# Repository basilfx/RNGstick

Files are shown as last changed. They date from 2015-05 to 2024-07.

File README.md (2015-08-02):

# RNGstick
Entropy stick for experimenting, generating and evaluating true random numbers.

Status: evaluating prototype.

## Introduction
This project provides a hardware random number generation with a customizable firmware for experimenting. A NE555 free-running oscillator is used, of which the clock drift is measured and used as a source of randomness. The stick can be used for feeding the Linux entropy pool for random numbers.

The firmware is configurable via a built-in command line.

## Background
The idea for this project is from a research project I conducted during my master's programme. Together with two others, we did a research on using accelerometers from mobile phones for generating true random numbers.

### True randomness
True random numbers (in contrast to pseudorandom numbers) are unpredictable. Given a number, the next number is not predictable and not linked to it. Computers cannot generate true random numbers via an algorithm, but they can observe physical events and extract uncertainty (entropy). For instance, mouse movement, disk access time and network traffic times are considered unpredictable. There is one problem: these events may occur not frequent enough, which means that the pool of entropy will exhaust. For general purpose random numbers, this is not a big deal, but for generating cryptographic keys, this becomes a problem.

An operating system does not directly generate numbers from this pool, but uses a pseudorandom algorithm that is seeded with the collected entropy. On Linux, `/dev/random` will block when the entropy pool is exhausted, but `/dev/urandom` won't. A quick experiment is to `cat /dev/random` and move the mouse around. You will notice the rate of numbers will increase (at least on Linux without HWRNG).

### Project rationale
In the last few years, processor manufacturers have incorporated hardware random number generators in processors. A kernel can use this source directly to generate random numbers, or to feed the entropy pool. However, with recent NSA leakings, some OS's have already [announced](http://www.theregister.co.uk/2013/12/09/freebsd_abandoning_hardware_randomness/) to not trust these output sources directly.

This project is an open-source attempt to generate random numbers of sufficien quality, using a low number of hardware parts. It is based on [this](http://1474orchard.ca/projects/?x=entry:entry120926-185104) blog post, where the author is using a NE555 free-running oscillator and uses the clock drift as a source of randomness. An Arduino samples the output of the NE555 regularly, which is a point on the waveform. Clock drift is affected by temperature, part stability, voltage and many more factors, that are unpredictable in some sense. In short, given two waveforms they won't be the same as one period may be a tiny bit shorter or longer. Using hardware parts with more tolerance (thus more error) is preferred.

The next two graphs the P(x) values of the ADC sample distribution over the full ADC sample space (10 bits) and the bit distribution (again, 10 bits). Both graphs match the ones from the blog post. Note how the lower 5 bits are uniformly distributed.

board

board

I have used this design and created an USB stick with a customizable firmware for generating random bytes. In addition to the original design, the NE555 can be reset before each iteration (to target the same sample point) and the voltage reference for the ADC is customizable. Many parameters can be tuned to generate random numbers in a different way. The following features are available:

* Sampling: batch-samples, or per-sample
* Sample processing: masking, shifting and delays
* Bit extracting: one-majority, XOR, or raw bits
* Extraction: (Improved) Von Neumann bias removal, or none
* Generating: SHA-1, or none
* Bucketing: buffer bytes to output chuncks, or continuously
* Outputting: (Binary) bytes or bits

To give an idea of the output, the following distribution of the P-values was created, using ones-majority over the lower five bits and bias removal using Improved Von Neumann, without any generator. One should be careful to call the output random from this graph only, because a predictable sequence from 0-255 over and over would generate a similar graph.

board

More graphs can be found [here](https://github.com/basilfx/RNGstick/blob/master/docs/Graphs.md).

### Testing
The problem with random numbers is that you cannot prove they are random. However, there are statistical tests which can indicate if a sequence of random numbers is 'random' enough. Even a sequence of numbers that doesn't look random could be random, as the random number generator could produce this sequence.

Three programs are available to check the produced sequences. The first is `ent`, which calculates the Entropy, Chi-square Distribution and the Arithmetic Mean Value. The second one is `rngtest`, which implements the FIPS 140-2 tests. The last one is `dieharder`, which implements a lot of different tests.

Sidenote: SHA-1 will generate more bytes of randomness for one input byte. In some sense it is a pseudorandom algorithm. Given the internal state, the next output bytes can be predicted if the next input byte is predictable. Since SHA-1 is a computational strong hash function, it will most-certainly pass all statistical tests by default.

TODO add test results here

## Contents
* Eagle schematic and PCB
* Arduino firmware

## Eagle

### Bill of materials
| Part | Value | Device | Package |
|---|---|---|---|
| C1 | 22pF | C-EUC0603K | C0603K |
| C2 | 22pF | C-EUC0603K | C0603K |
| C3 | 22pF | C-EUC0603K | C0603K |
| C4 | 22pF | C-EUC0603K | C0603K |
| C5 | 10nF | C-EUC0603K | C0603K |
| C6 | 100nF | C-EUC0603K | C0603K |
| C7 | 100nF | C-EUC0603K | C0603K |
| C8 | 100nF | C-EUC0603K | C0603K |
| D1 | | PESD5V0U1BB | SOD523 |
| D2 | | PESD5V0U1BB | SOD523 |
| IC1 | | NE555D | SO08 |
| JP1 | USB-A-H | USB-A-H | USB-A-H |
| JP4 | M02PTH | M02PTH | 1X02 |
| R1 | 5K | TRIM_EU-3223W | 3223W |
| R2 | 330R | R-EU_R0603 | R0603 |
| R3 | 10k | R-EU_R0603 | R0603 |
| R4 | 10k | R-EU_R0603 | R0603 |
| U2 | | CH340G | SOIC16 |
| U1 | | ATMEGA328 | TQFP32-08 |
| Q1 | 16MHz | MT-OSCILLATOR | MT |
| Q2 | 12MHz | MT-OSCILLATOR | MT |

### Board render
Render of the stick. It measures 1.45x0.65 inch.

board

## Firmware
The firmware resides in `firmware/RNG`. You will need a copy of the [CommandLine](https://github.com/basilfx/Arduino-CommandLine) library and the [Cruiptosuit](https://github.com/spaniakos/Cryptosuite/) library.

Modify the `Arduino/CommandLine/CommandLine.h` file to reflect the following (see its `README.md` file why):

```
#define COMMANDLINE_COUNT 24
#define COMMANDLINE_BUFFER 24
// #define COMMANDLINE_PRE_POST
#define COMMANDLINE_HISTORY 0
```

## Software

### Configuration
To configure the stick, short JP4 while booting. A setup prompt should appear. Use the `help` command to list all available commands. Do not forget to save a change using the `save` command. Use `defaults` or `load` respectively.

### Installation
This will install `rng-tools` for feeding the random numbers back into the kernel. It applies to Ubuntu 15.04, but others will work fine too. `/dev/ttyACM0` is assumed to be the RNGstick.

* Instal `rng-tools` via `sudo apt-get install rng-tools`
* Change `/etc/defaults/rng-tools`
 * Add `stty -F /dev/ttyACM0 115200 time 25`
 * Add `HRNGDEVICE=/dev/ttyACM0`
* Restart `rng-tools` with `sudo service rng-tools restart`
* Observe `/proc/sys/kernel/random/entropy_avail`

## License
See the `LICENSE` file (MIT license).

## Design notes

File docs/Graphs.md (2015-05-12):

# Output graphs

## ADC Values
Graphs below are the ADC P(x) distributions.

board

board

board

board

## Bit values
Graphs below are the individual P(x) value distributions.

board

## RNG values
Graphs below are the P(x) value distributions of the RNG output values (1-256).

board

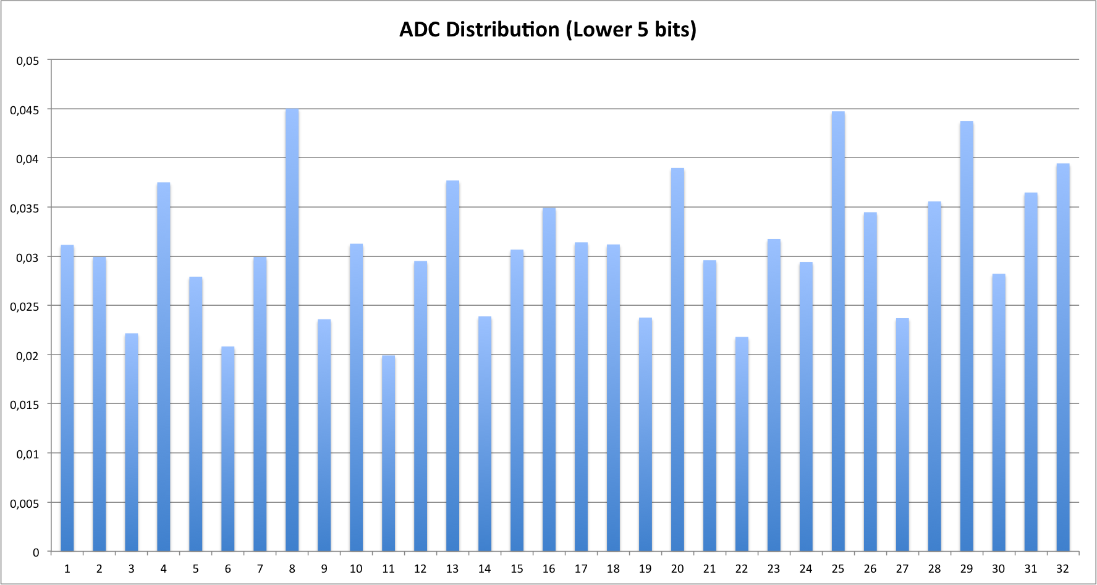
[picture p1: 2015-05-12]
docs/adc_5bits.png

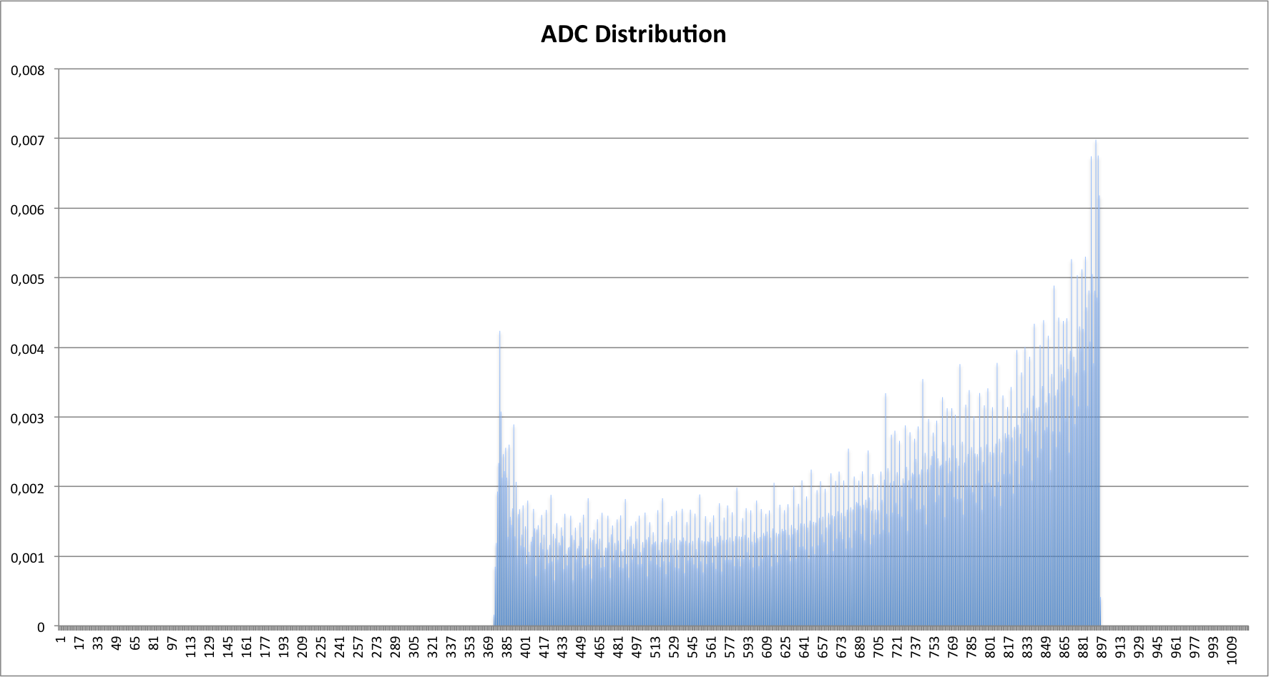
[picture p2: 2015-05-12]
docs/adc_10bits.png

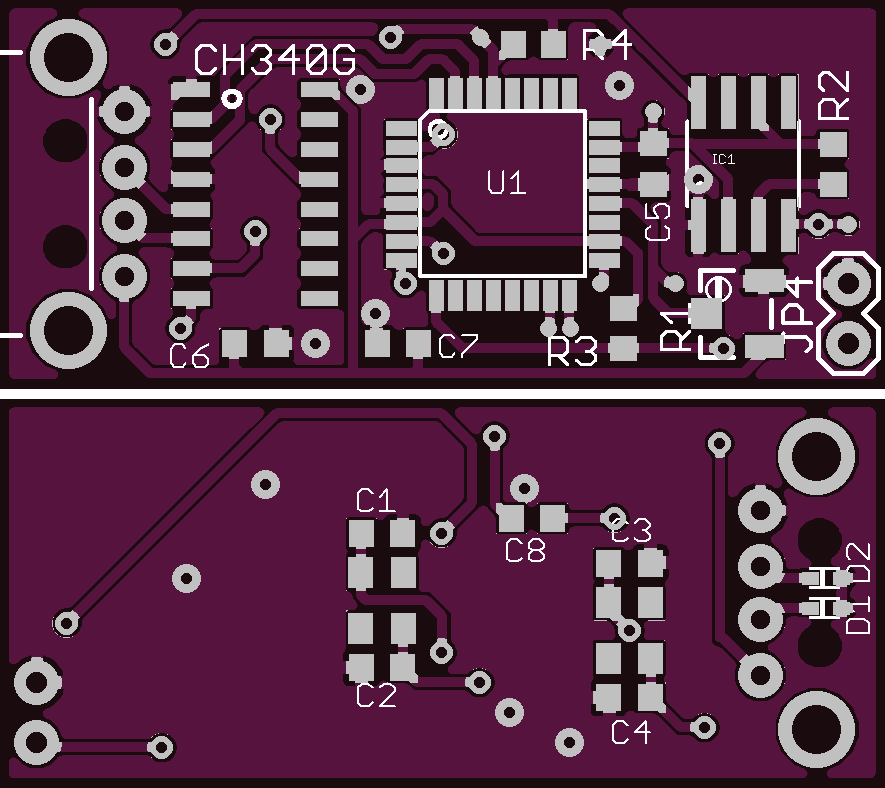
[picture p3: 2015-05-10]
docs/stick.png

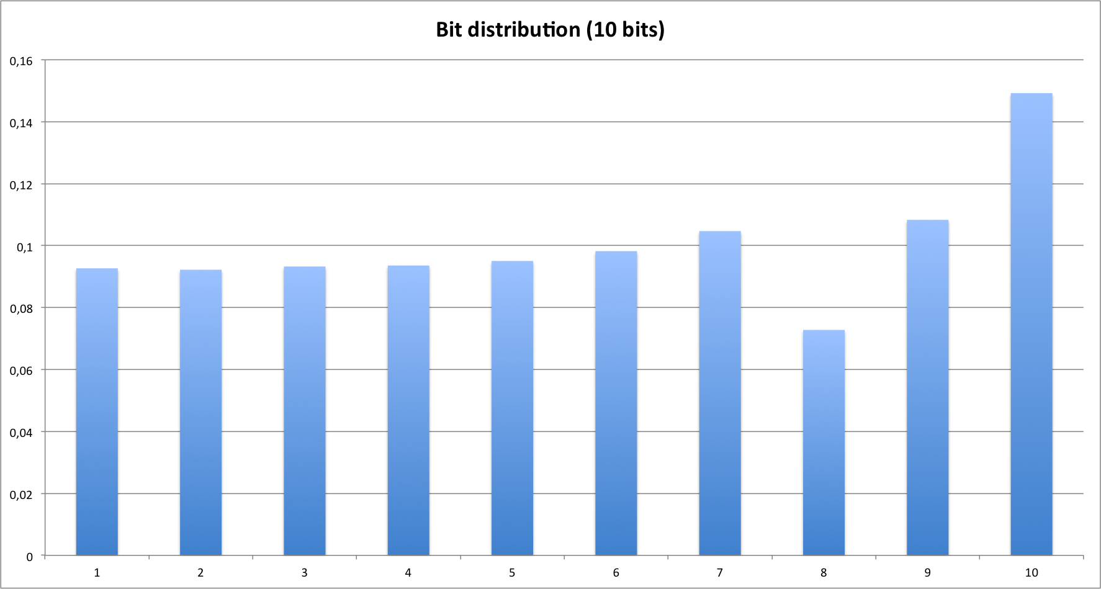
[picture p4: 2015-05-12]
docs/bit_distribution.png

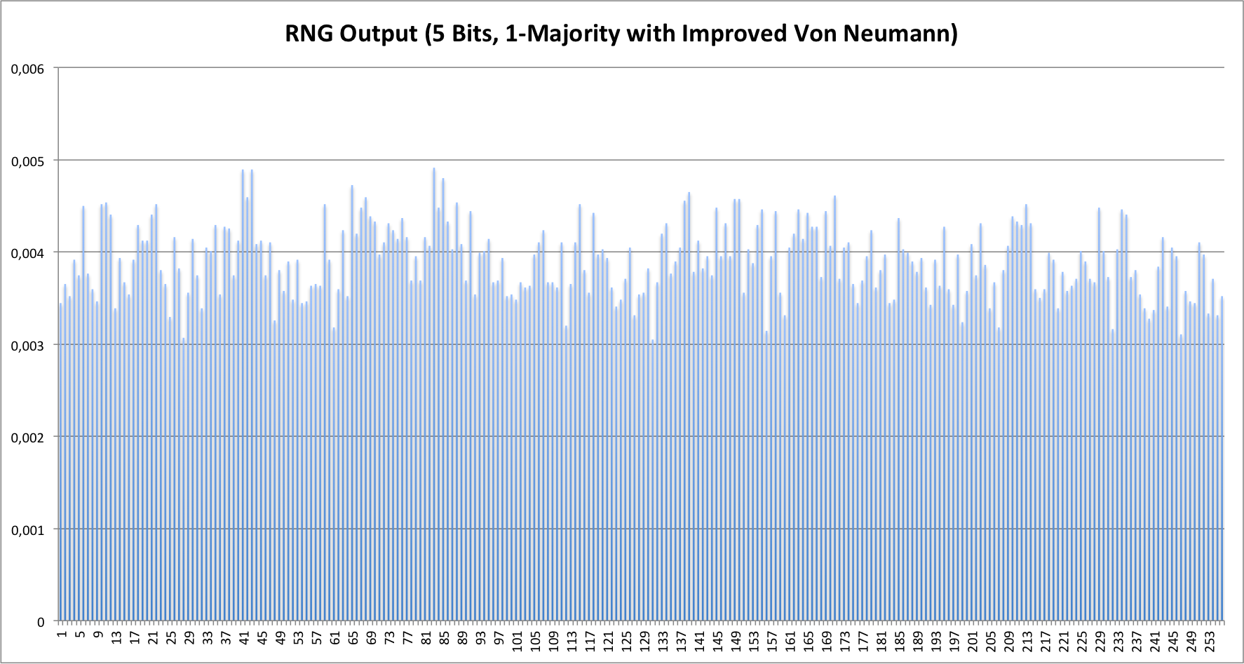
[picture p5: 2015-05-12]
docs/rng_out.png

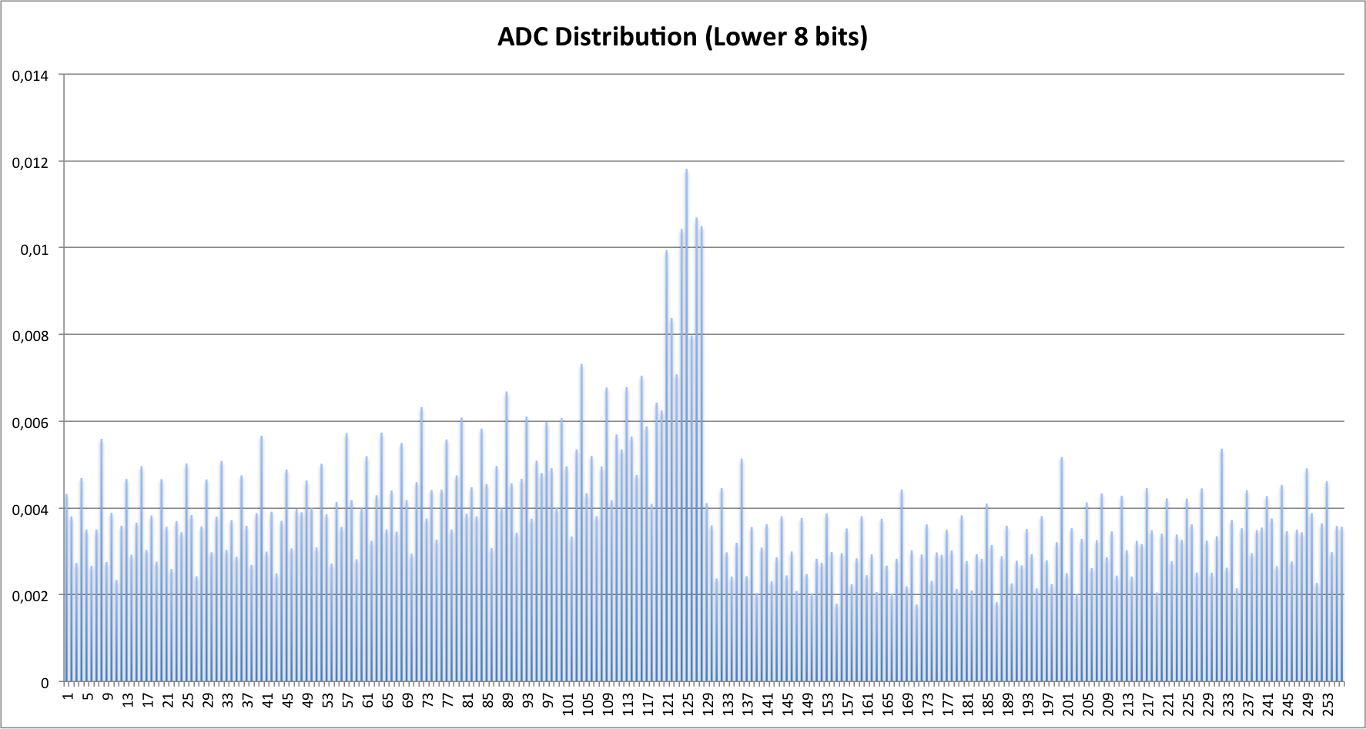
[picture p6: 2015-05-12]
docs/adc_8bits.png

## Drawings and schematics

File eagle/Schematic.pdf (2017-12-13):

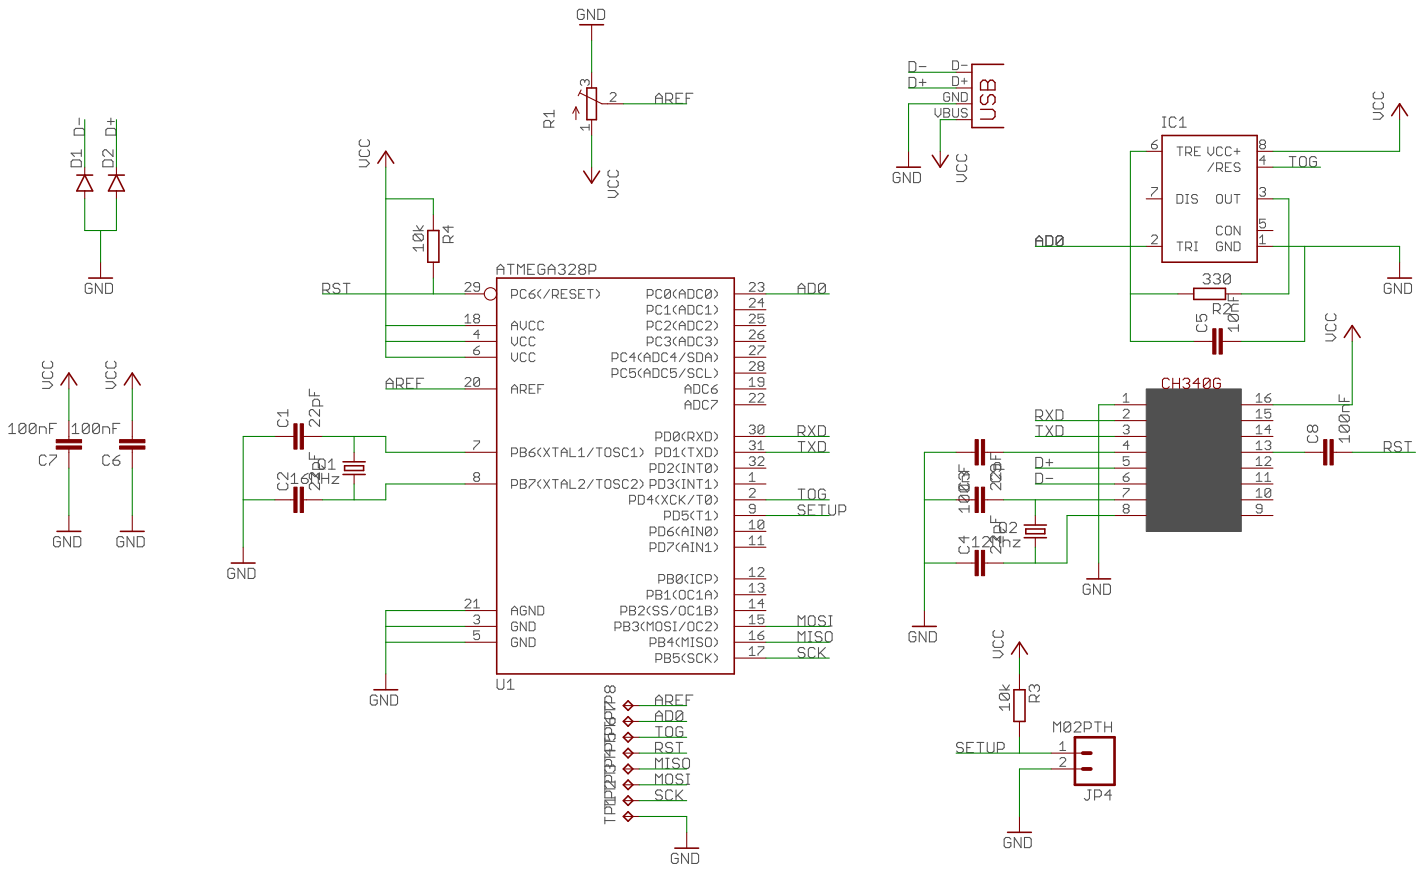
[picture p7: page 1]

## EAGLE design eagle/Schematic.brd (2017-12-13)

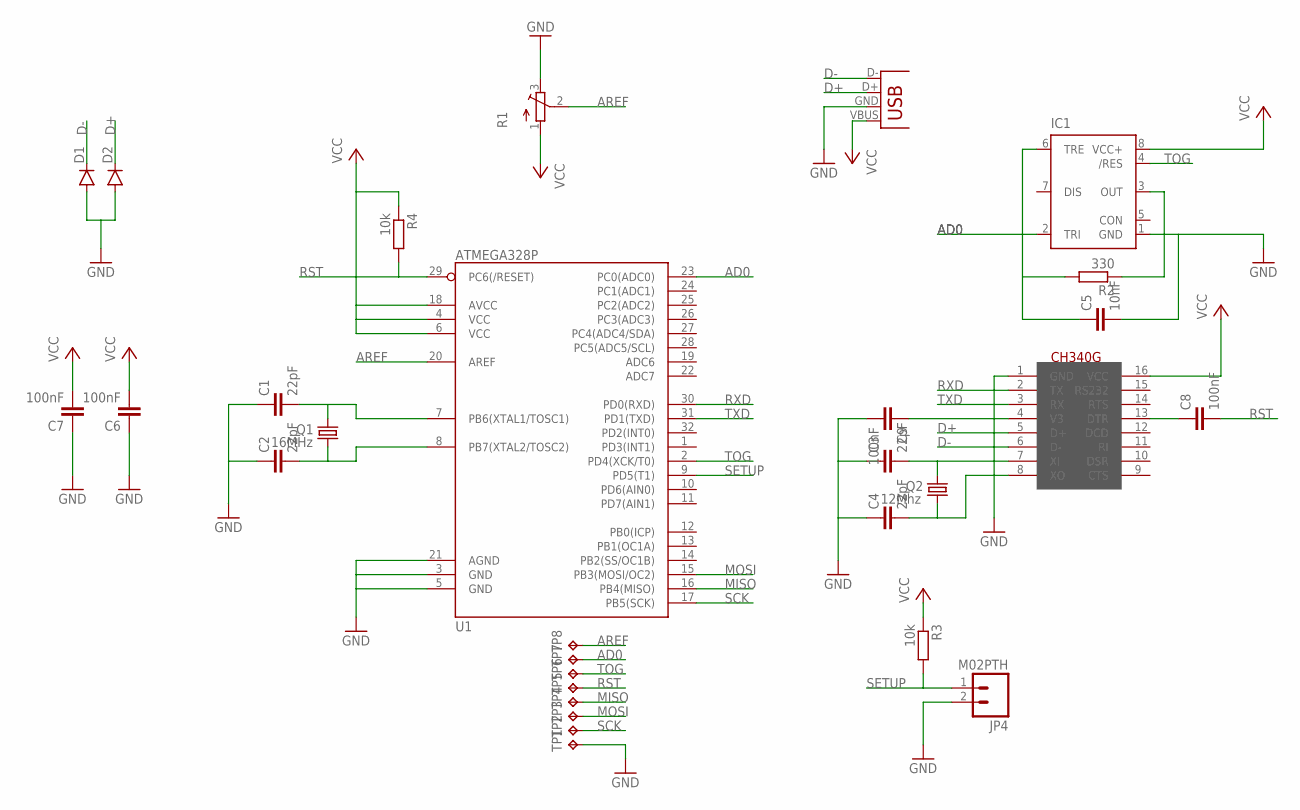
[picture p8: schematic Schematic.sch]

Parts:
C1, C2, C3, C4: 22pF; C0603K
C5: 10nF; C0603K
C6, C7, C8, C9: 100nF; C0603K
D1, D2: DIODESOD523; SOD523
IC1: NE555D; SO08
JP1: USB-A-H
JP4: M02PTH; 1X02
Q1: 16MHz; MT
Q2: 12Mhz; MT
R1: TRIM_EU-3223W; 3223W
R2: 330; R0603
R3, R4: 10k; R0603
TP1, TP2, TP3, TP4, TP5, TP6, TP7, TP8: TPTP10R; TP10R
U1: ATMEGA328P; TQFP32-08
U2: CH340G; SOIC16

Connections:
AD0: C5.1, IC1.2 (TRI), IC1.6 (TRE), R2.2, TP7.TP, U1.23 (PC0(ADC0))
AREF: R1.2 (S), TP8.TP, U1.20 (AREF)
D+: D2.C, JP1.D+ (D-), U2.5 (D+)
D-: D1.C, JP1.D- (D+), U2.6 (D-)
GND: C1.1, C2.1, C3.1, C4.1, C5.2, C6.1, C7.1, C9.2, D1.A, D2.A, IC1.1 (GND), JP1.GND (VBUS), JP4.2, R1.3 (E), TP1.TP, U1.3 (GND), U1.5 (GND), U1.21 (AGND), U2.1 (GND)
MISO: TP4.TP, U1.16 (PB4(MISO))
MOSI: TP3.TP, U1.15 (PB3(MOSI/OC2))
unnamed: IC1.3 (OUT), R2.1
unnamed: C3.2, Q2.3 (2), U2.7 (XI)
unnamed: C4.2, Q2.1, U2.8 (XO)
unnamed: C1.2, Q1.3 (2), U1.7 (PB6(XTAL1/TOSC1))
unnamed: C2.2, Q1.1, U1.8 (PB7(XTAL2/TOSC2))
unnamed: C8.1, U2.13 (DTR)
unnamed: C9.1, U2.4 (V3)
RST: C8.2, R4.2, TP5.TP, U1.29 (PC6(/RESET))
RXD: U1.30 (PD0(RXD)), U2.2 (TX)
SCK: TP2.TP, U1.17 (PB5(SCK))
SETUP: JP4.1, R3.2, U1.9 (PD5(T1))
TOG: IC1.4 (/RES), TP6.TP, U1.2 (PD4(XCK/T0))
TXD: U1.31 (PD1(TXD)), U2.3 (RX)
VCC: C6.2, C7.2, IC1.8 (VCC+), JP1.VBUS (GND), R1.1 (A), R3.1, R4.1, U1.4 (VCC), U1.6 (VCC), U1.18 (AVCC), U2.16 (VCC)

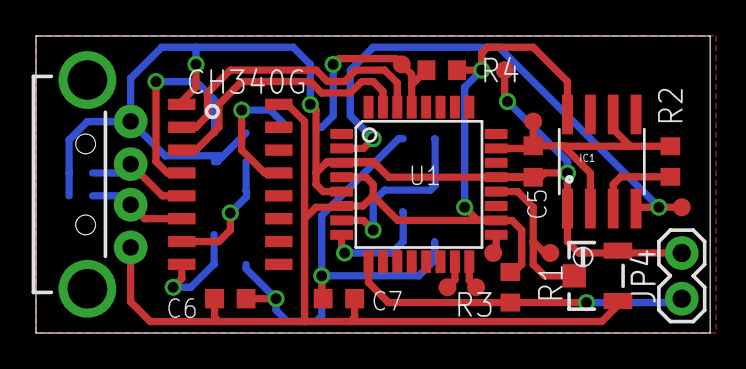
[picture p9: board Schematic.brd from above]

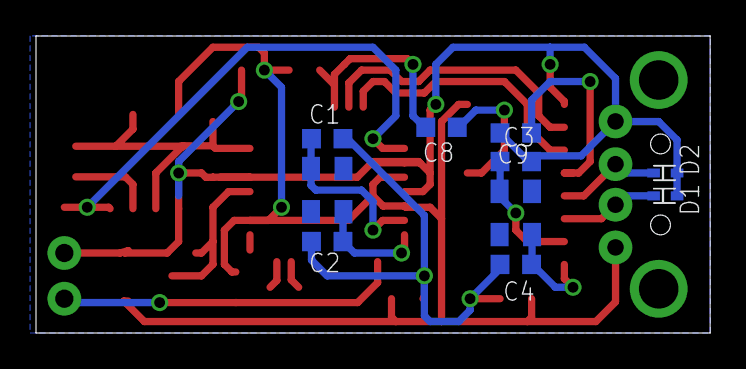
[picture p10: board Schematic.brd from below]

Board: 2 copper layers, 37.5 x 16.5 mm, 30 parts (10 on the bottom side), 21 nets.

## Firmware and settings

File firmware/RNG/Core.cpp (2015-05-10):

#include "Core.h"

/**
 * Sample bucket
 */
volatile uint16_t sampleBucket[256];

/**
 * Process buffer
 */
volatile uint16_t processBuffer[2];
volatile uint8_t processBufferCount;

/**
 * Extraction buffer
 */
volatile uint16_t extractBuffer;
volatile uint8_t extractBufferCount;

/**
 * Generate buffer
 */
volatile uint16_t generateBuffer;
volatile uint8_t generateBufferCount;

/**
 * Output buffer
 */
volatile uint16_t outputBuffer;
volatile uint8_t outputBufferCount;

/**
 * Output bucket
 */
volatile uint8_t outputBucket[256];
volatile uint16_t outputBucketIndex;

void output(uint8_t value) 
{ 
  if (configuration.outputMode == 1) {
    Serial.write(value);
  } else if (configuration.outputMode == 2) {
    Serial.print(value, DEC);
  } else if (configuration.outputMode == 3) {
    Serial.println(value, DEC); 
  }
}

void bucket(uint8_t value)
{
  outputBucket[outputBucketIndex] = value;
  outputBucketIndex++;
  
  if (outputBucketIndex >= configuration.outputBucket) {
    while (true) {
      outputBucketIndex--;
      output(outputBucket[outputBucketIndex]);
      
      if (outputBucketIndex == 0) {
        break;
      }
    }
  }
}

void collect(uint8_t value, uint8_t count)
{ 
  outputBuffer = (outputBuffer << count) | value;
  outputBufferCount = outputBufferCount + count;
  
  while (outputBufferCount > 7) {
    if (configuration.output == 1) {
      for (uint8_t i = 0; i < 8; i++) {
        bucket((uint8_t) (outputBuffer & 0x01));
        outputBuffer = outputBuffer >> 1;
      }
    } else if (configuration.output == 2) {
      bucket((uint8_t) (outputBuffer & 0xFF));
      outputBuffer = outputBuffer >> 8; 
    }
    
    outputBufferCount = outputBufferCount - 8; 
  }
}

void generate(uint8_t value, uint8_t count)
{
  if (configuration.generator == 1) {
    collect(value, count);
  } else if (configuration.generator == 2) {
    generateBuffer = (generateBuffer << count) | value;
    generateBufferCount = generateBufferCount + count;
    
    while (generateBufferCount > 7) {
      Sha1.print((uint8_t) (generateBuffer & 0xFF));
      uint8_t* result = Sha1.result();
      
      for (uint32_t i = 0; i < 20; i++) {
         collect(result[i], 8);
      }
      
      generateBuffer = generateBuffer >> 8;
      generateBufferCount = generateBufferCount - 8;
    }
  }
}

void extract(uint8_t value, uint8_t count)
{ 
  if (configuration.extractor == 1) {
    generate(value, count);
  } else if (configuration.extractor == 2 || configuration.extractor == 3) {
    extractBuffer = (extractBuffer << count) | value;
    extractBufferCount = extractBufferCount + count;
  
    while (extractBufferCount > 3) {
      if (configuration.extractor == 2) {
        generate(VON_NEUMANN[extractBuffer & 0x0F][0], VON_NEUMANN[extractBuffer & 0x0F][1]);
      } else if (configuration.extractor == 3) {
        generate(IMPROVED_VON_NEUMANN[extractBuffer & 0x0F][0], IMPROVED_VON_NEUMANN[extractBuffer & 0x0F][1]);
      }
     
      extractBuffer = extractBuffer >> 4;
      extractBufferCount = extractBufferCount - 4; 
    }
  }
}

void process(uint16_t sample)
{
  sample = (sample & configuration.sampleMask) >> configuration.sampleShift;
  
  if (configuration.mode == 1) {
    extract(sample, configuration.sampleTake);
  } else if (configuration.mode == 3) {
    processBuffer[processBufferCount] = sample;
    processBufferCount++;

    if (processBufferCount == 2) {
      extract(processBuffer[0] ^ processBuffer[1], configuration.sampleTake);
    }
  } else if (configuration.mode == 2) {
    uint8_t count = 0;
    
    for (uint8_t i = 0; i < configuration.sampleTake; i++) {
      if (sample & (1 << i)) {
        count++;
      }
    }

    extract(count > (configuration.sampleTake / 2) ? 1 : 0, 1);
  }
}

void loop()
{
  // Reset the NE555
  if (configuration.sampleReset == 1) {
    digitalWrite(4, LOW);
    delayMicroseconds(configuration.delayHold);
    digitalWrite(4, HIGH);
    delayMicroseconds(configuration.delaySkip);
  }
  
  // Take samples
  for (uint16_t i = 0; i < configuration.sampleMultiple; i++) {
    // Gather samples
    for (uint16_t j = 0; j < configuration.sampleBucket; j++) {
      sampleBucket[j] = analogRead(A0);
    }
    
    // Process samples
    for (uint16_t j = 0; j < configuration.sampleBucket; j++) {
      process(sampleBucket[j]);
    }
  }
  
  // Round delay
  delayMicroseconds(configuration.delayRound); 
}

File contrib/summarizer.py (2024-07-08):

import sys
import os
import formic

# Tests to disable
DISABLED_TESTS = [
    "dab_bytedistrib",
    "marsaglia_tsang_gcd",
    "rgb_minimum_distance",
    "rgb_kstest_test"
]

PROPERTIES = {
    "sampleReset": ("Sample reset", lambda x: "Yes" if x else "No"),
    "sampleBucket": ("Sample bucket size", lambda x:  "%s b" % x),
    "sampleMultiple": ("Sample multiple", lambda x: "%s b" % x),
    "delayHold": ("Sample hold", lambda x: "%s us" % x),
    "delaySkip": ("Sample skip", lambda x:  "%s us" % x),
    "delayRound": ("Delay round", lambda x: "%s us" % x),
    "sampleMask": ("Sample mask", hex),
    "sampleShift": ("Sample shift", str),
    "sampleTake": ("Sample take", str),
    "mode": ("Mode", lambda x: "Raw" if x == 1 else "Ones-majority"),
    "extractor": ("Extractor", lambda x: "None" if x == 1 else "Von Neumann" if x == 2 else "Improved Von Neumann"),
    "generator": ("Generator", lambda x: "None" if x == 1 else "SHA-1"),
    "output": ("Output", lambda x: "Bits" if x == 1 else "Bytes"),
    "outputMode": ("Output mode", lambda x: "Raw" if x == 1 else "ASCII" if x == 2 else "ASCII + Newline"),
    "outputBucket": ("Output bucket", lambda x: "%s b" % x)
}


def main(argv):
    if len(argv) < 2:
        sys.stdout.write("Syntax: %s <input_dir>\n" % argv[0])
        return 1

    input_dir = os.path.abspath(argv[1])

    # Find files
    file_set = formic.FileSet(include="**/*.diehard", directory=input_dir)
    filenames = list(file_set)

    # Print header
    sys.stdout.write("ID,File size,ENT,Entropy,Chi-square,Mean,Monte-Carlo-Pi,Serial-Correlation,DIEHARDER,Total,Passed,Failed,Weak,CONFIGURATION,")
    sys.stdout.write(",".join([x[0] for x in PROPERTIES.itervalues()]) + "\n")

    for filename in filenames:
        # Resolve filenames
        test_id = os.path.basename(filename).rsplit(".", 1)[0]
        filename_dh = filename
        filename_conf = filename.rsplit(".", 1)[0] + ".txt"
        filename_ent = filename.rsplit(".", 1)[0] + ".ent"
        filename_data = filename.rsplit(".", 1)[0] + ".bin"

        file_size = os.stat(filename_data).st_size

        # Initialize counters
        total = 0
        weak = 0
        failed = 0
        passed = 0
        state = 0

        # Read DIEHARDER file and scan for test results
        with open(filename_dh, "r") as fp:
            for line in fp:
                # Search for 'test_name'
                if state == 0:
                    # Unpack line
                    parts = map(lambda x: x.strip(), line.split("|"))

                    if parts[0] == "test_name":
                        state = 1

                # Next line is comment
                elif state == 1:
                    state = 2

                # Read all test results
                elif state == 2:
                    # Test for test end
                    if line[:3] == "#==":
                        state = 0
                        continue

                    # Split results
                    parts = map(lambda x: x.strip(), line.split("|"))

                    # Unpack line
                    try:
                        test_name, ntup, tsamples, psamples, p_value, assessment = parts
                    except ValueError:
                        continue

                    # Check if test is not ignored
                    if test_name in DISABLED_TESTS:
                        continue

                    # Count results
                    total += 1

                    if assessment == "FAILED":
                        failed += 1
                    elif assessment == "PASSED":
                        passed += 1
                    elif assessment == "WEAK":
                        weak += 1

        # Read Ent file
        with open(filename_ent, "r") as fp:
            lines = []

            for line in fp:
                lines.append(line.strip())

            ent = lines[1].split(",", 1)[1]

        # Read configuration file
        sys.stdout.write("%s,%s,%s,%s,%s,%s,%s,%s,%s,%s,%s,%s,%s,%s," % (test_id, file_size, "", ent, "", "", "", "", "", total, passed, failed, weak, ""))

        with open(filename_conf, "r") as fp:
            configuration = eval(fp.read())

            for key, value in PROPERTIES.iteritems():
                sys.stdout.write(value[1](configuration[key]))
                sys.stdout.write(",")

        sys.stdout.write("\n")

    # Done
    return 0

# E.g. `python main.py input'
if __name__ == "__main__":
    sys.exit(main(sys.argv))

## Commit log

2015-05-09 Initial commit.
    [Schematic.brd, Schematic.sch]
2015-05-10 Added sample bucket and XOR.
2015-05-10 Added DTR reset, converted XTAL to smaller ones.
    [Schematic.brd, Schematic.sch]
2015-05-10 Converted strings to PROGMEM to save memory. Tweak buckets for maximal memory usage.
2015-08-02 Reduce sample size. 256kb will take ages.
2017-12-12 Fix output mode command.
    [Commands.cpp]
2017-12-13 Fix PCB errors after first prototype.
    [Schematic.brd, Schematic.sch]

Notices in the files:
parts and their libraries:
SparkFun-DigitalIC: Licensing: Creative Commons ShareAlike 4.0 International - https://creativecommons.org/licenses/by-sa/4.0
